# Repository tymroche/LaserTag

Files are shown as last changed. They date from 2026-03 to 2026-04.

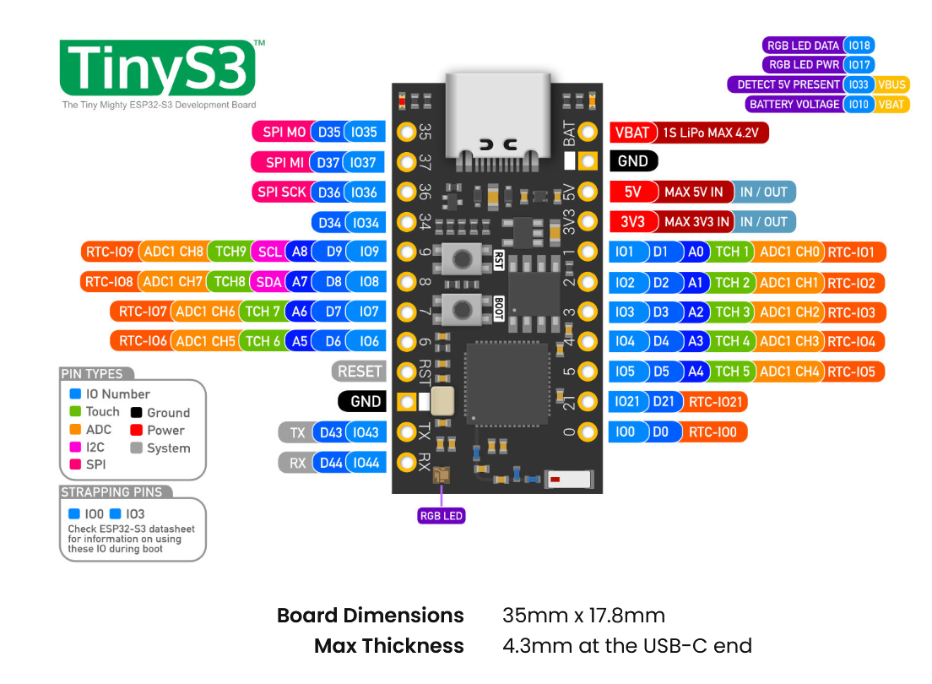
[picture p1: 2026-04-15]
Documents/ESP32s3_Pinout.png

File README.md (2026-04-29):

# Laser Tag

## Purpose
The purpose of the Laser Tag project is to create an entirely custom portable battery-powered laser-tag game, where multiple players can wirelessly interface with a server that contains game logic, and can fire "lasers" (invisible signals) at each other to play the game.

---

## Components

### Adafruit 5639 IR LED Emitter
38 kHz IR emitter used to transmit encoded data packets between players. Activated by trigger input.

### Adafruit 5939 IR Remote Receiver
38 kHz IR receiver used to demodulate incoming data packets from other players. Output routed as an external interrupt.

### SPST Button
Trigger input used to initiate encoding and transmission of the player's ID.

### ESP32-C6 Development Kit

**Server Module**
Hosts a SoftAP, HTTP server, and TCP server, managing all network communication:
- Accepts incoming player messages and distributes game state and player information via TCP.
- Handles HTTP requests to update and deliver information to the web interface.

**Player Module**
Communicates with the server and manages all core functions:
- Encodes and transmits player's ID as an IR data frame via the emitter on button interrupt.
- Decodes incoming IR data from the receiver interrupt.
- Drives audio feedback to the speaker via PWM.

### PWM Speaker
Audio feedback device used to signal the player of game events, including:
- Power on
- Connected
- Disconnected
- Player Hit
- Low Health
- Player Dead
- Fire (Enabled)
- Fire (Disabled)
- Win
- Lose

### Battery Housing / Batteries / SPDT Switch
Three 1.5V AA batteries wired in series, supplying 4.5V to the ESP32-C6. Housed in a 3×AA battery casing with an SPDT switch for power control.

### Vest & Velcro
T-shirt worn by the player to serve as a mounting surface for the game modules. Velcro used to attach and secure each module to the vest.

> Refer to the [project slideshow](LaserTag.pptx) for a fully labelled component diagram.
---

## System Overview
Each player is equipped with two receivers (one on the front-mounted player module and one on the back-mounted standalone module), one handheld emitter, and a battery pack. Upon powering on, each player module will automatically connect to the server. To select a game mode, configure game settings, and start the game, connect to the server's Wi-Fi and navigate to the game website at `192.168.4.1`.

---

## Game Logic
There are two game modes for Laser Tag: Free-For-All and Duels.

### Free-For-All
Players compete for the duration set by the website timer. Starting from 0, each hit landed adds 100 points and each hit received deducts 50. The player with the most points when the timer expires wins. Equal scores result in a draw.

### Duels
Players compete until one player remains (or none). Each player starts with 5 HP, which decrements by 1 for every hit received. The last player with nonzero HP wins. If all remaining players reach 0 HP simultaneously, there is no winner.

---

## Encountered Issues

### IR Timing
During testing, we noticed that transmitted bits were not being received correctly. After hardware debugging and analyzing the signals with an oscilloscope, we found that the receiver was detecting everything as expected, just with the incorrect timing. We had not accounted for the overhead between bit transmissions, meaning the firmware was sending bits every ~500 µs when they were being transmitted every ~700 µs. Once identified, we measured the overhead and adjusted the timing accordingly in both transmission and reception, resolving the issue. This overhead will be re-measured and recalibrated after every firmware change.

### Watchdog Timer
When designing the trigger logic, the IR write function was initially placed inside the interrupt handler. The button worked correctly until this logic was introduced, at which point the watchdog timer began tripping. We determined that the write function was taking too long within the interrupt, causing the watchdog to trigger before the write could complete. This was resolved by having the interrupt simply set a flag, which is then polled in the main loop. This immediately fixed the issue.

### Website Refresh Bug
HTTP requests were completed and parsed via the website URL, which caused page refreshes to retain the previous URL extension and repeat the last user action. This was resolved by implementing a helper function that clears the URL after each action and redirects back to the root IP address.

### Dev. Board Challenges
The UM TinyS3 was initially chosen as the MCU for both the server and player modules due to its Wi-Fi capabilities, strong performance, and compact form factor. In practice, however, it struggled to reliably host the servers and maintain player connections in areas of significant interference. Despite having a better antenna than the ESP32-C6 DevKit, its Wi-Fi 4 protocol appeared to be the bottleneck, prompting the switch to the ESP32-C6. The ESP32-C6 was able to reliably host the server and maintain player connections, though the platform change introduced IR timing issues that required recalibration before the system functioned correctly.

---

## Differences & Similarities to Commercial Laser Tag
We wanted our version of laser tag to be as close to the real thing as possible, and the core requirements to get there are simple. At its core, players get to shoot lasers at each other. Most implementations track different statistics (who was hit the most, who was the most accurate, who was the most trigger-happy, etc.). However, what makes ours stand out is not just that we track who hits who, but we do it by encoding the player ID directly into the IR transmission. On top of that, the immediate audio feedback keeps players informed on if they can fire, when they have fired, and when they've been hit.

Because our server is entirely portable, you can play anywhere you like. You can even adjust game settings from any internet-capable device by connecting directly to our server and using the hosted website. This works at any time the server is running, with no limit on how many devices can connect at once.

Our solution is also significantly cheaper than any commercial laser tag system you would find online.

---

## Future Improvements
The following improvements are planned for Laser Tag v2:

| Improvement | Description |
|---|---|
| **Custom Module Housing** | 3D-printed enclosures for the server and each player sub-module. |
| **Proper Vests** | Sewn-on fastening system for a cleaner, more permanent solution. |
| **Rechargeable Battery Power** | Lithium-Ion batteries to replace the current AA battery packs on both modules. |
| **Migration to STM** | Transition away from the ESP32 to the more industry-standard STM platform. |
| **Multi-Threading** | Enable simultaneous IR transmission and reception on player modules via multi-threading. |
| **Antenna** | Add antennas to the server and player modules for improved connection, reliability, and range. |
| **PCBs** | Design and fabricate custom boards for each sub-module for better connectivity and a smaller form factor. |
| **Live Website Updates** | Rewrite the front-end in JavaScript to push live updates, eliminating the need for a page refresh. |

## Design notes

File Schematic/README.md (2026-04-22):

Laser Tag Game
Creates local host server
Creates html at ip
Communication between server and client via TCP
  Process hits
  Parse URL
Generates encoded IR packets to communicate between players
  Start bit low, Start bit high, 8 bit player data, even parity bit, stop bit high
Receivers demodulate IR signal and communicates information to host
Trigger button triggers interrupt flags to fire IR
Receivers trigger interrupt flag on falling edge of IR reception
Audio feedback played through speaker

Espressif ESP32c6 - Host Protocols, creates softAP, webserver for http, and device server for tcp.

Espressif ESP32c6 x3 - Player Protocols, creates wifi station and joins host network. Communicates with server via tcp.

Adafruit IR Remote Receiver x6 - Falling edge IR signal triggers interrupt flags to prepare receiver to decode IR packet.
Packet is then communicated to device server.

Adafruit High Power IR LED Emitter x3 - Trigger flags prompt emitter to send IR packet encoded with PlayerID.

Button - Triggers interrupt on rising edge to set Trigger flag high to prompt Emitter fire.

Speaker - Plays audio.

Problems encountered - alot.

IR timing change due to overhead.

Watchdog timer button instead of trigger button.

Website url refresh bug.

WiFi pain. ESP32C6 pain.

Similar - 

Different - 

Improvements -

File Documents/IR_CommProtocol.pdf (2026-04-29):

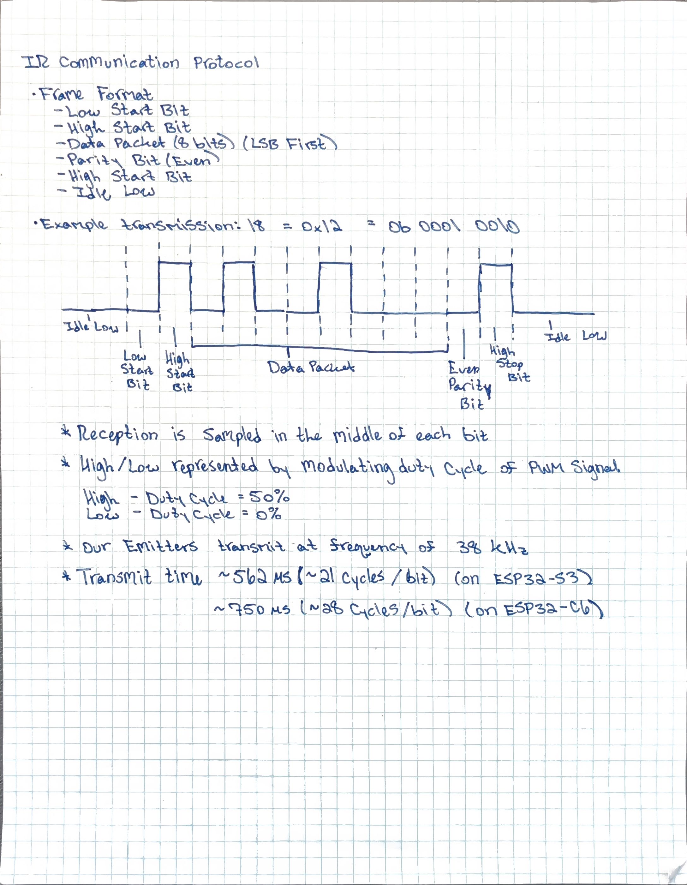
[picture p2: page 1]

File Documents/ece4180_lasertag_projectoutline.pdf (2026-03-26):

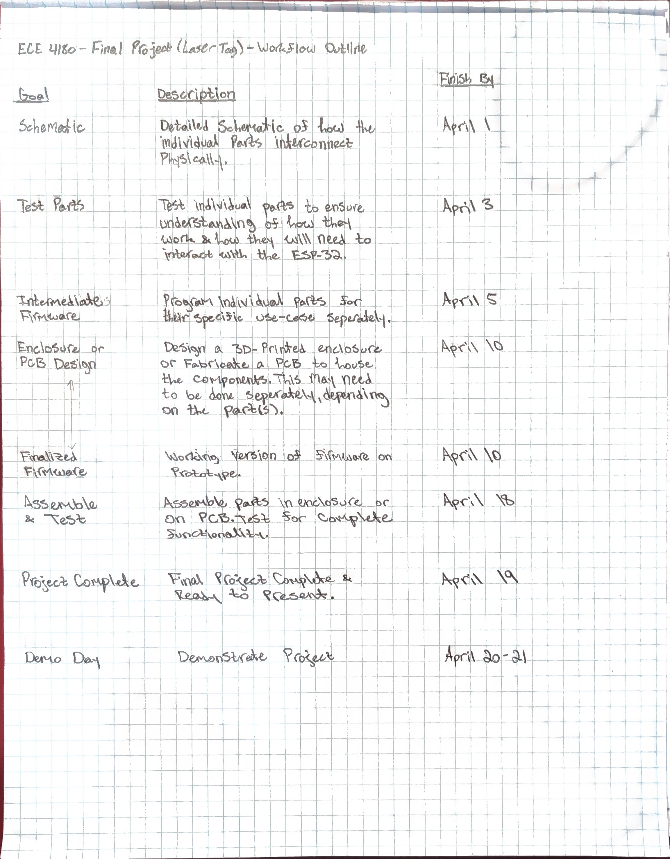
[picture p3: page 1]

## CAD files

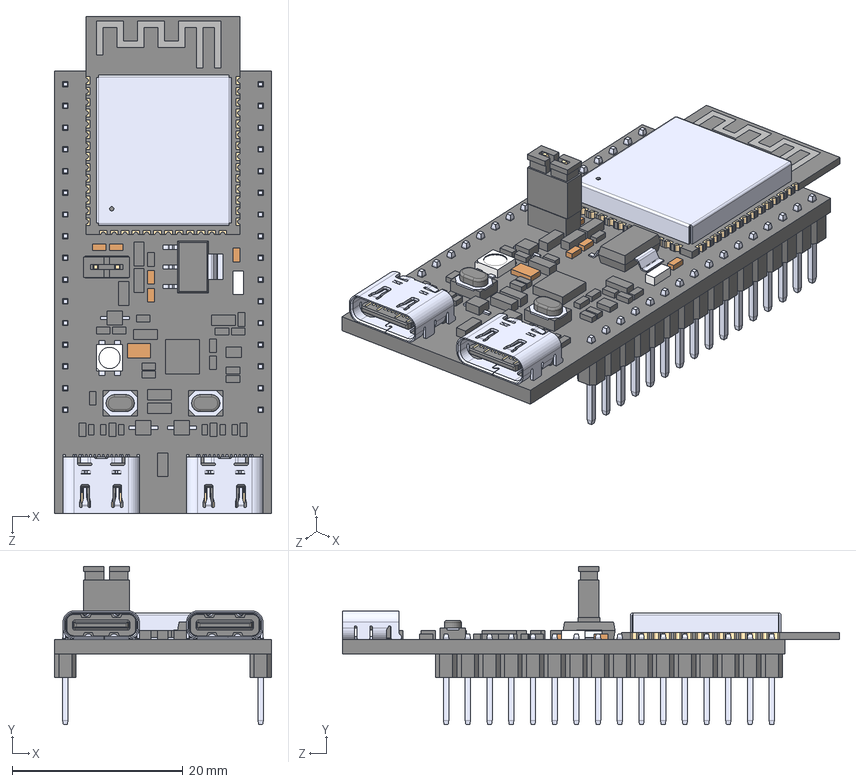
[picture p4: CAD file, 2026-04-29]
Schematic/Symbols_and_Footprints/ESP32-C6-DEVKITC-1-N8/ESP32-C6-DEVKITC-1-N8.step
25.4 x 18.5 x 58.2 mm

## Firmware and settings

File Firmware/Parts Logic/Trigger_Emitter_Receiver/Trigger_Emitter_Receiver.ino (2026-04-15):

#define TRIGGER_SWITCH          2                               /** Trigger SPST Input (triggers interrupt) */
#define EMITTER_OUT             3                               /** PWM Output to Emitter */
#define RECEIVER_IN             6                               /** IR Receiver Input */
#define EMITTER_FREQ            38000                           /** Frequency of PWM Output */
#define PWM_RESOLUTION          8                               /** Resolution for PWM Duty Cycle */
#define DUTY_CYCLE_50           ((1 <<  PWM_RESOLUTION) / 2)    /** 50% Duty Cycle based on Resolution */
#define DUTY_CYCLE_0            0                               /** 0% Duty Cycle regardless of Resolution */
#define BIT_TRANSMIT_TIME_US    562                             /** Time that 1 bit is transmitted for.  */   



/** MACRO FUNCTIONS  */
/** 
* @brief Wrapper function for ledcWrite used.
* @param duty Duty cycle to set PWM to. 
*/
inline void pwm_write(uint8_t duty) {
  ledcWrite(EMITTER_OUT, duty);
}

/** 
* @brief Wrapper functin for delayMicroseconds. 
* @note Used for Bit Transmission. 
*/
inline void transmitDelay() {
  delayMicroseconds(BIT_TRANSMIT_TIME_US);
}

/** 
* @brief Wrapper function for delayMicroseconds.
* @note Used for Bit Reception. 
*/
inline void receiveDelay() {
  delayMicroseconds(BIT_TRANSMIT_TIME_US);
}

/** 
* @brief Wrapper function for delayMicroseconds. 
* @note Used for Reception Timing Offset to center readings. */
inline void receiveTimeOffset() {
  delayMicroseconds(BIT_TRANSMIT_TIME_US / 2);
}



/** ENUM DECLARATIONS  */
/** Status Enum. */
typedef enum {
  INVALID_INPUT,
  BAD_WRITE,
  START_ERROR,
  STOP_ERROR,
  PARITY_ERROR,
  STATUS_OK
} status_t;



/** GLOBAL VARIABLES  */
// Trigger Debouncing 
unsigned long lastTrigger = 0;
volatile bool rxFlag = false;
// Temp Variables (Used for Testing)
volatile int numTrigger = 0;
uint8_t transmitData = 80;
uint8_t receiveData = 0;



/** FORWARD DECLARATIONS  */
status_t emitter_write(uint8_t data);
status_t receiverRead(volatile uint8_t* buffer);
void printStatus(status_t status);



/** INTERRUPT SERVICE ROUTINES (ISRs) */
/**
* @brief Interrupt Handler for trigger button. 
* @note Includes debounce logic. 
*/
void IRAM_ATTR trigger_isr() {
  if ((millis() - lastTrigger) < 200) return;
  lastTrigger = millis();
  emitter_write(transmitData);
  numTrigger++;
}

/**
* @brief Interrupt Handler for receiver signal. 
*/
void IRAM_ATTR receiver_isr() {
  rxFlag = true;
}



/** GENERAL PURPOSE FUNCTIONS */
/** 
* @brief Transmits data over IR emitter. 
* @param data Data to be written.
* @return INVALID_INPUT if Data is Null, BAD_WRITE if write failed, STATUS_OK if write successful.
* @note Package format: 2 Start Bits (First Low, Second High), 8 Data bits (LSB First), 1 Parity Bit [Even], 1 Stop Bit (High).
* @note Bit period of 21 cycles. 21 Cycles @ 38kHz will transmit 1 bit. Baud: 1809 bits / sec.
*/
status_t emitter_write(uint8_t data) {

  // Initialize Local Variables
  uint8_t numHighBits = 0;

  // Transmit start bits (1 Low, 1 High)
  pwm_write(DUTY_CYCLE_0);
  transmitDelay();

  pwm_write(DUTY_CYCLE_50);
  transmitDelay();

  // Transmit data bits (8 Total) LSB First
  for (uint8_t i = 0; i < 8; i++) {
    if (data & 0x1) {
      pwm_write(DUTY_CYCLE_50);
      numHighBits++;
    } else {
      pwm_write(DUTY_CYCLE_0);
    }
    data >>= 0x1;
    transmitDelay();
  }

  // Calculate & Transmit Parity Bit
  pwm_write((numHighBits % 2) ? DUTY_CYCLE_50 : DUTY_CYCLE_0);
  transmitDelay();

  // Transmit stop bit (1 High)
  pwm_write(DUTY_CYCLE_50);
  transmitDelay();

  // Idle Low
  pwm_write(DUTY_CYCLE_0);

  return STATUS_OK;
}

/** 
* @brief Receives transmitted receiveData. 
* @param buffer Buffer to store read receiveData in.
* @return INVALID_INPUT if receiveData is Null, PARITY_ERROR if parity does not match, STATUS_OK if read successful.
* @note Receiver inverts all signals when demodulated.
* @note Interrupt triggered via polled flag.
* @note Reads in the middle of bit periods.
*/
status_t receiverRead(volatile uint8_t* buffer) {
  if (buffer == NULL) {
    return INVALID_INPUT;
  }

  // Initialize Local Variables
  uint8_t numHighBits = 0;
  *buffer = 0;

  // Centers read to middle of bit period
  receiveTimeOffset();

  // Reads bits & Stores in buffer
  for (int i = 0; i < 8; i++) {
    receiveDelay();
    uint8_t currVal = !digitalRead(RECEIVER_IN);
    *buffer |=  (currVal << i);
    if (currVal) {
      numHighBits ++;
    }
  }

  // Compares Parity Bit
    receiveDelay();    
    if (!digitalRead(RECEIVER_IN) != (numHighBits % 2)) { // compare parity
      return PARITY_ERROR;
    }

  // Checks Stop Bit
  receiveDelay();
  if (digitalRead(RECEIVER_IN)) {
    return STOP_ERROR;
  }

  return STATUS_OK;
}



/** SETUP FUNCTIONS */
/**
 * @brief Helper function that initializes Trigger Pin & Attaches ISR
 * @note Used in setup
 */
void trigger_init() {
  pinMode(TRIGGER_SWITCH, INPUT_PULLDOWN);
  attachInterrupt(TRIGGER_SWITCH, trigger_isr, RISING);
}

/**
 * @brief Helper function that initializes Emitter Pin & Attaches PWM
 * @note Used in setup
 */
void emitter_init() {
  pinMode(EMITTER_OUT, OUTPUT);
  ledcAttach(EMITTER_OUT, EMITTER_FREQ, PWM_RESOLUTION);
}

/**
* @brief Helper function that initializes Receiver Pin & Attaches ISR
* @note Used in setup
*/
void receiver_init() {
  pinMode(RECEIVER_IN, INPUT);
  attachInterrupt(RECEIVER_IN, receiver_isr, FALLING);
}



/** ARDUINO FUNCTIONS */
void setup() {
  // Initializes Serial Debugging
  Serial.begin(115200);
  Serial.println("Serial Initialized!");

  // Initialize Trigger
  trigger_init();

  // Initialize Emitter
  emitter_init();

  // Initialize Receiver
  receiver_init();
}

void loop() {  
  if (rxFlag) {
    printStatus(receiverRead(&receiveData));
    Serial.printf("Received receiveData: %d\n", receiveData);
    Serial.flush();
    rxFlag = 0;
  }
}



/** PRINT FUNCTIONS */
/** 
* @brief Helper function to print based on status.
* @param status Status to print.
*/
void printStatus(status_t status) {
  switch (status) {
    case INVALID_INPUT: Serial.println("Status: INVALID_INPUT");  break;
    case BAD_WRITE:     Serial.println("Status: BAD_WRITE");      break;
    case START_ERROR:   Serial.println("Status: START_ERROR");    break;
    case PARITY_ERROR:  Serial.println("Status: PARITY_ERROR");   break;
    case STOP_ERROR:    Serial.println("Status: STOP_ERROR");     break;
    case STATUS_OK:     Serial.println("Status: OK");             break;
    default:            Serial.println("Status: UNKNOWN");        break;
  }
}

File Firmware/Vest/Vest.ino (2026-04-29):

/**
 * @file Vest.ino
 * @author Alfonso Landaverde, Tyler Roche
 * @date 4/15/2026
 * @version 1.0
 *
 * @brief Main File for ESP32S3
 * Contains all wifi protocols, all emitter and receiver methods, audio DAC controls, and power
 */

#include <Arduino.h>
#include <WiFi.h>
#include "Vest-Wifi-Protocol.h"
#include "player_comms.h"
#include "speaker.h"

/**
 * @brief setup vest
 */
void setup() {
  Serial.begin(115200);

  speaker_init();
  delay(1000);
  playStartUpBeeps();
  WiFi.mode(WIFI_STA);
  WiFi.begin(hostSsid, hostPassword);
  Serial.println(hostSsid);
  Serial.println(hostPassword);
  delay(2000);

  //testing
  Serial.print("Trying to join SSID: ");
  Serial.println(hostSsid);

  // Initialize Transmit Variables
  rxFlag = false;
  rxFlag2 = false;
  receiveData = 0;
  transmitData = 152;
  triggerFlag = false;

  // Initialize Trigger
  trigger_init();

  // Initialize Emitter
  emitter_init();

  // Initialize Receiver
  receiver_init();
}

/**
 * @brief main super loop
 */
void loop() {
  static uint8_t previousHp = currentHp;
  static bool previousAlive = alive;

  if (connectVestToHost()) {
    playConnectedBeeps();
  }
  handleHostMessages();

  // Only play damage/death sounds when state changes
  if (currentHp < previousHp) {
    playGotHitBeeps();

    if (currentHp == 0 && previousAlive) {
      playDeadBeeps();
    } else if (currentHp > 0 && currentHp < 3) {
      playLowHealthBeeps();
    }
  }

  previousHp = currentHp;
  previousAlive = alive;

  if (currentTimer == 0) {
    rxFlag = false;
    rxFlag2 = false;
    receiveData = 0;
  }

  transmitData = playerIdToByte(assignedPlayerId);

  if (triggerFlag) {
    triggerFlag = false;

    if (vestCanFire()) {
      emitter_write(transmitData);
      playFireBeeps();
      Serial.println("Shot fired");
    } else {
      playCantFireBeeps();
    }
  }

  if (rxFlag) {
    rxFlag = false;

    status_t status = receiverRead(&receiveData, RECEIVER_IN);
    printStatus(status);
    Serial.printf("Received receiveData on RECEIVER_IN: %d\n", receiveData);

    if (status == STATUS_OK) {
      String attackerId = byteToPlayerId(receiveData);

      if (attackerId.length() > 0 &&
          attackerId != assignedPlayerId &&
          alive &&
          canShoot &&
          currentTimer > 0) {
        reportHitToHost(attackerId);
      }
    }
  }

  if (rxFlag2) {
    rxFlag2 = false;

    status_t status = receiverRead(&receiveData, RECEIVER_IN_2);
    printStatus(status);
    Serial.printf("Received receiveData on RECEIVER_IN_2: %d\n", receiveData);

    if (status == STATUS_OK) {
      String attackerId = byteToPlayerId(receiveData);

      if (attackerId.length() > 0 &&
          attackerId != assignedPlayerId &&
          alive &&
          canShoot &&
          currentTimer > 0) {
        reportHitToHost(attackerId);
      }
    }
  }
}

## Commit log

2026-03-26 Added Project Outline
    [LaserTag.kicad_sch]
2026-04-04 Schematic 1.0 Compelte, Passes ERC
    [LaserTag.kicad_sch, temp.kicad_pcb, temp.kicad_sch]
2026-04-04 Receiver & Emitter Test Firmware Complete
    [temp.kicad_sch]
2026-04-06 Added Comparator Logic to Receiver Schematic
    [LaserTag.kicad_sch]
2026-04-08 Added 10k pull-up resistor to drive comparator out
2026-04-08 Added Aux Header Symbol + Organization
    [LaserTag.kicad_sch]
2026-04-14 Updated emitter Schematic.
    [LaserTag.kicad_sch]
2026-04-14 Added I2S DAC Headphone Out to Schematic
    [LaserTag.kicad_sch]
2026-04-14 included push button in schematic
    [LaserTag.kicad_sch]
2026-04-14 Corrected AUX Schematic
    [LaserTag.kicad_sch]
2026-04-14 Debugging continued. Still bugs in there.
    [Trigger_Emitter_Receiver.ino]
2026-04-15 Fixed typos in change from .io to .cpp/.h/.io
    [Host-Server.cpp]
2026-04-19 Fixed a lot of bugs, everything is now working together-- some gameplay needs bugfixing still; hardware works flawlessly
    [Host-Server.cpp, Vest-Wifi-Protocol.cpp, Vest2.ino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]
2026-04-22 attempting speaker fix
    [LaserTag.kicad_sch]
2026-04-29 Tyler told me to get rid of the useless files :(
    [temp.kicad_pcb, temp.kicad_sch]
2026-04-29 Latest folder updates
    [ESP32-C6-DEVKITC-1-N8.step, LaserTag.kicad_pcb, LaserTag.kicad_sch]
2026-04-29 Added Documentation & Videos / Pictures
    [LaserTag.kicad_sch]
2026-04-29 Added LaserTag Presentation
2026-04-29 Actually Added LaserTag.pptx
2026-04-29 Trying again to add LaserTag.pptx
2026-04-29 I lied, i fixed typos
    [Vest.ino, Vest3.ino]
